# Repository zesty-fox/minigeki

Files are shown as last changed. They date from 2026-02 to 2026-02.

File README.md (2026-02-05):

# ONGEKI Mini Controller

**语言 / Language:** [English](./README_en.md)

这是用于 SEGA 的街机音游 ONGEKI（音击）设计的（不）迷你控制器。

这个仓库基于 [Lee65535/Minigeki](https://github.com/Lee65535/Minigeki) 和 [HanasakiMana/Minigeki](https://github.com/HanasakiMana/Minigeki) 进行魔改。

成品如图：

完成品照片
侧面照片

## 结构

整体结构参考了 Lee 的五层板设计和 Hanasaki 的扩大尺寸的 PCB 板设计。

- 整体大小约为 250mm $\times$ 200mm $\times$ 13.3mm；
- 最底层是一个带有脚垫的底板，厚度 1.6mm；
- 下夹层是一个 5mm 厚的亚克力板；
- 中间层为 PCB 板（由 Hanasaki 设计），厚度 1.6mm；
- 上夹层是一个 3.5mm 厚的亚克力板；
- 最顶层是一个 1.6mm 厚的面板，兼顾定位板功能。
- 整体通过 6 组 M3*18 杯头螺丝和盖型螺母固定，其中杯头螺丝自下而上穿过各层，每个杯头外套一个硅胶平头套用作脚垫。

为了节省时间，我的上下夹层平面设计相同（只有厚度不同）。

### 如果想要组装

你需要的元件有：

- 1 个 SparkFun Pro Micro 单片机（或仿品）
- 10 颗键轴及键帽，推荐其中 2 颗键帽使用 1.75U 或 2U 大小用于侧键
- 10 个热插拔轴座
- 10 颗 WS2812B LED 灯珠，当然由于 LED 十分难焊，不需要 LED 也可以不装
- 1 个 75mm、类型 B10K 的双联直滑电位器（也就是调音台上的推子）。
  - 类型的含义如下：第 1 位代表变化类型，A 为对数变化，B 为线性变化；后面代表最大电阻，10K 代表 10 千欧姆，50K 代表 50 千欧姆；
  - 我使用了 ALPS RS60112A6A0C 来替换原方案的 NOBLE XJV60GPV15C-15A20K，因为后者是对数变化而不适用；
  - 上面可以再加装一个 3D 打印的仿官机手柄（由原作者设计）。

对于总体结构：

- PCB 板直接去找厂家下单；
- 对于上下夹层，可以拿平面图找商家定制即可。我采用了黑色亚克力，当然你可以尝试 POM 或者 EVA 棉等更好的材料；
- 对于顶层和底层，铝合金或者 FR4 材质都是不错的选择。我这里直接设计了空的 PCB 板（FR4）充当顶层和底层。
- 可以用各类在线模型查看器来查看仓库中模型的实际效果。

此外还有连接件：

- 6 颗 M3*18 杯头螺丝
- 6 颗 M3 盖型螺母
- 6 个硅胶平头套（用作脚垫），推荐内径 5.1mm、内高 3.5mm（我也不知道为什么商家会有这么完全适配的尺寸）

## 软件

由于未知原因，我刷入原作者的 mu3controller 固件后摇杆和按键触发都相当不稳定，因此我最后选择魔改了原作者 Lee 的键鼠固件。

直接用 PlatformIO 编译并刷入目录下的 firmware-B 固件即可。当然如果你不幸买到了 A 型电位器，可以尝试 firmware-A 固件，其包含了对电位器曲线的调整。

### 关于魔改的原因

原键鼠固件由于采用相对位移方式实现鼠标移动，由于鼠标加速度和累计误差的因素，很容易导致滑杆漂移。

我修改为了将滑杆位置映射为鼠标绝对坐标，解决了这个问题。

## 文件结构

- `Minigeki keyboard firmware-*\`：固件源码
- `img\`：一些图片
- `model\`：模型文件
  - `top_pcb\`：顶层空 PCB 板
  - `above_PCB.step`：上夹层
  - `under_PCB.step`：下夹层
  - `layer.dxf`：夹层平面图
  - `top.step`：顶层面板
  - `bottom.step`：底层面板
  - `mini knob.STL`：滑杆手柄

## License

MIT

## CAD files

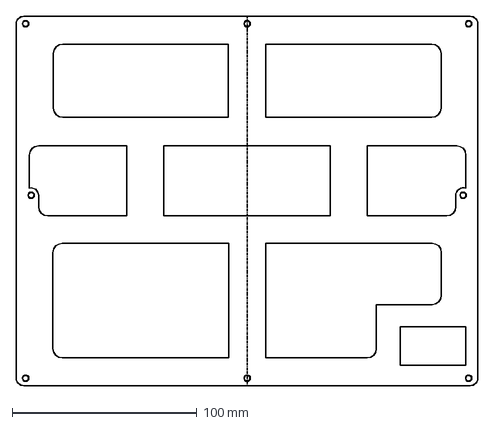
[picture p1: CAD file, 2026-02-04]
model/layer.dxf
250.0 x 200.0 mm

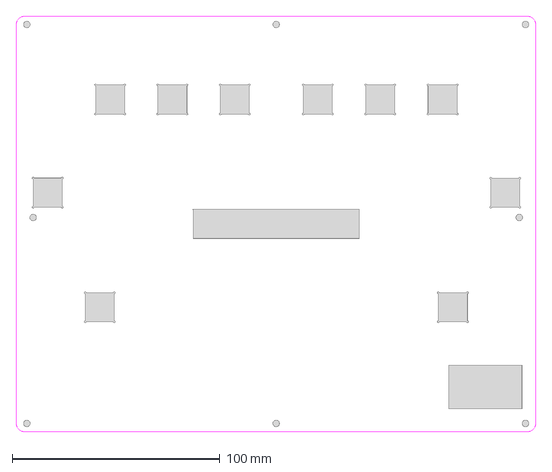
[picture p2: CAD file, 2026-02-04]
model/top_pcb/DXF_PCB1_2026-01-23_AutoCAD2007.dxf
250.1 x 200.1 mm

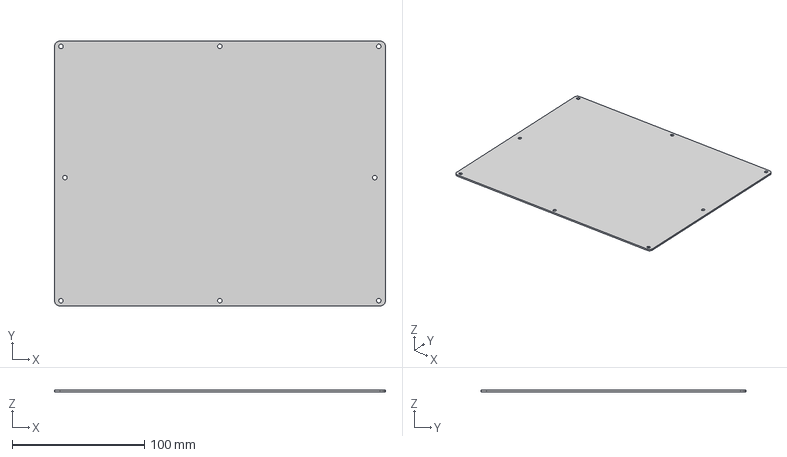
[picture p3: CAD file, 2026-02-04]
model/bottom.step
250.0 x 200.0 x 1.60 mm

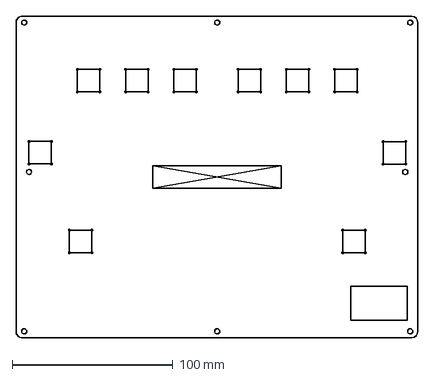
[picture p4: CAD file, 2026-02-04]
model/top_pcb/top_board.dxf
250.0 x 200.0 mm

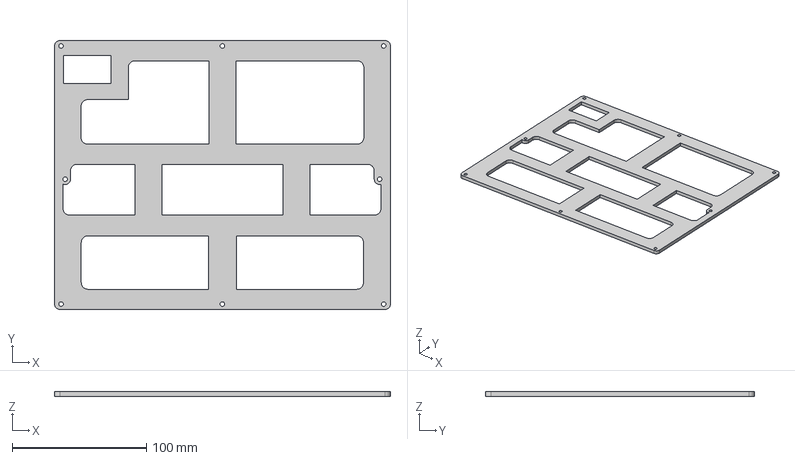
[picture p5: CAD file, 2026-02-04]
model/above_PCB.step
250.0 x 200.0 x 3.50 mm

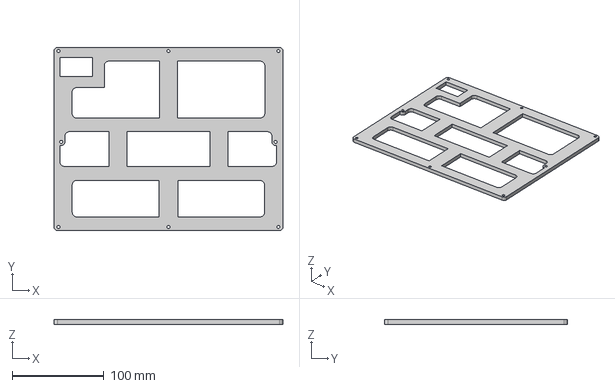
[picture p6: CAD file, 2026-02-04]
model/under_PCB.step
250.0 x 200.0 x 5.00 mm

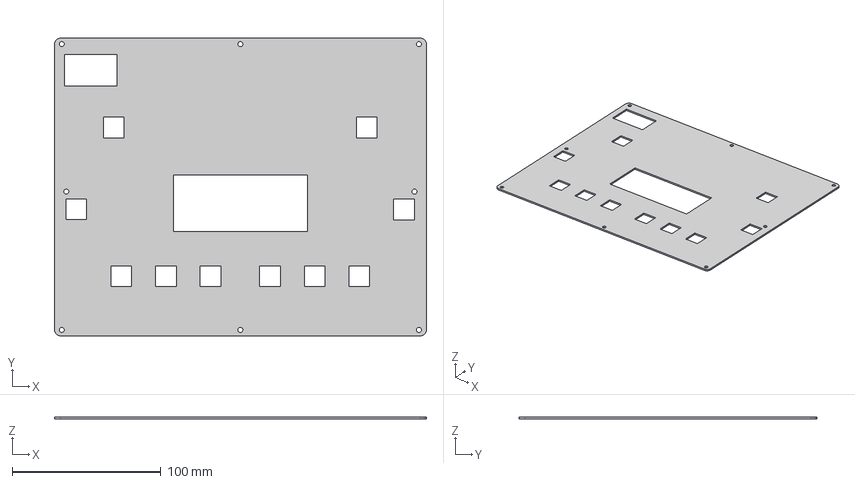
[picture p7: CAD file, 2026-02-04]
model/top.step
250.0 x 200.0 x 1.50 mm

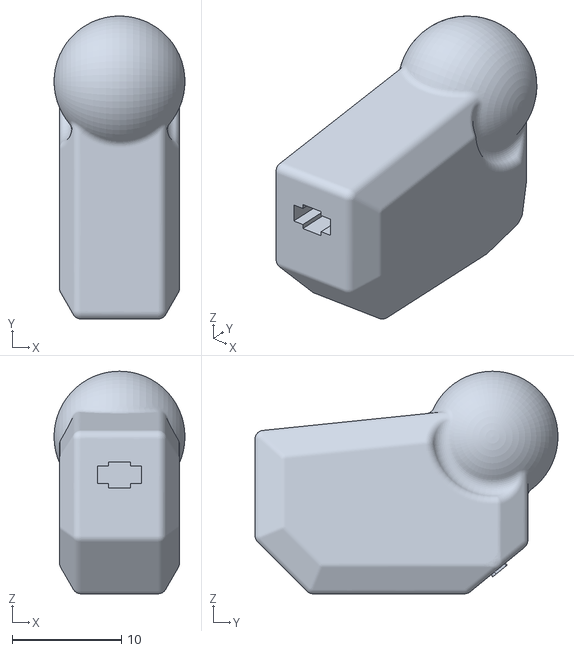
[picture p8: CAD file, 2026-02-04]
model/mini knob.STL
12.0 x 27.8 x 20.4

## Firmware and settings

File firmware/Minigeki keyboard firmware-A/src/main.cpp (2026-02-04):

#include "main.hpp"

// Pinout
#define LED_PIN PIN_A1
#define LEVER_PIN PIN_A0
#define LSIDE_LED_PIN 16
#define RSIDE_LED_PIN 10

// Some color preset
const CRGB GOLDEN_YELLOW = 0xFFEE40;
const CRGB SAKURA_PINK = 0xFF8080;

// Yes you can change as you wish
const int KEY_MAP[10] = {
    // L: A    B    C   SIDE MENU
    'a', 's', 'd', KEY_RIGHT_ARROW, 'u',
    // R: A    B    C   SIDE MENU
    'j', 'k', 'l', KEY_LEFT_ARROW, 'o'};
const CRGB KEY_COLOR = SAKURA_PINK;

// Do not modify
const uint8_t PIN_MAP[10] = {
    // L: A B C SIDE MENU
    1, 0, 4, 14, 8,
    // R: A B C SIDE MENU
    5, 6, 7, 15, 9};
bool is_pressed[10];
bool updated[10];
int last_lever_value = -1;
CRGB lightColors[6];
const uint8_t COLOR_MAP[6] = {7, 6, 5, 2, 1, 0}; // 哈哈 我写出来自己都看不懂
CRGB leftSideColors[1];
CRGB rightSideColors[1];

int multiMap(int val, int *_in, int *_out, uint8_t size) {
  // 边界处理
  if (val <= _in[0])
    return _out[0];
  if (val >= _in[size - 1])
    return _out[size - 1];

  // 寻找输入值所在的区间
  uint8_t pos = 1;
  while (val > _in[pos])
    pos++;

  // 类似于 map() 函数，但只针对当前的一小段区间
  if (val == _in[pos])
    return _out[pos];

  // 数学公式: y = y0 + (x - x0) * (y1 - y0) / (x1 - x0)
  return (val - _in[pos - 1]) * (long)(_out[pos] - _out[pos - 1]) /
             (_in[pos] - _in[pos - 1]) +
         _out[pos - 1];
}

uint16_t p_15A_to_joystick(int rawInput) {
  if (rawInput < 0)
    rawInput = 0;
  if (rawInput > 1023)
    rawInput = 1023;

  static const int in[] = {0, 4, 14, 29, 75, 142, 226, 460, 787, 994, 1023};
  static const int out[] = {0,   0,   128, 256,  384, 512,
                            640, 768, 896, 1023, 1023};

  return multiMap(rawInput, (int *)in, (int *)out, sizeof(in) / sizeof(in[0]));
}

void setup() {
  for (unsigned char i : PIN_MAP) {
    pinMode(i, INPUT_PULLUP);
  }
  memset(is_pressed, 0, 10);
  FastLED.addLeds<WS2812B, LSIDE_LED_PIN, GRB>(leftSideColors, 1);
  FastLED.addLeds<WS2812B, RSIDE_LED_PIN, GRB>(rightSideColors, 1);
  FastLED.addLeds<WS2812B, LED_PIN, GRB>(lightColors, 6);
  Keyboard.begin();
  // Mouse.begin();
  AbsMouse.init(1920, 1080);
}

void loop() {
  // KEYBOARD
  for (auto i = 0; i < 10; i++) {
    bool read = digitalRead(PIN_MAP[i]) == LOW;
    if (read == true && is_pressed[i] == false) {
      is_pressed[i] = true;
      updated[i] = true;
      Keyboard.press(KEY_MAP[i]);
    } else if (read == false && is_pressed[i] == true) {
      is_pressed[i] = false;
      updated[i] = true;
      Keyboard.release(KEY_MAP[i]);
    } else {
      updated[i] = false;
    }
  }
  // MOUSE
  int read = 0;

  for (auto i = 0; i < 8; i++) {
    read += p_15A_to_joystick(analogRead(LEVER_PIN)) >> 3; // debounce
  }
  
  AbsMouse.move(map(read, 0, 1024, 960-128, 960+128), 540);
  // LED
  // single_color_when_pressed();
  random_color_when_pressed();
}

void random_color_when_pressed() {
  for (auto i = 0; i < 6; i++) {
    if (updated[COLOR_MAP[i]])
      lightColors[i] =
          is_pressed[COLOR_MAP[i]] ? get_rand_color() : CRGB::Black;
  }
  if (updated[3])
    leftSideColors[0] = is_pressed[3] ? get_rand_color() : CRGB::Black;
  if (updated[8])
    rightSideColors[0] = is_pressed[8] ? get_rand_color() : CRGB::Black;
  FastLED.show();
}

void single_color_when_pressed() {
  for (auto i = 0; i < 6; i++) {
    if (updated[COLOR_MAP[i]])
      lightColors[i] = is_pressed[COLOR_MAP[i]] ? KEY_COLOR : CRGB::Black;
  }
  if (updated[3])
    leftSideColors[0] = is_pressed[3] ? KEY_COLOR : CRGB::Black;
  if (updated[8])
    rightSideColors[0] = is_pressed[8] ? KEY_COLOR : CRGB::Black;
  FastLED.show();
}

void always_on() { FastLED.showColor(KEY_COLOR); }
